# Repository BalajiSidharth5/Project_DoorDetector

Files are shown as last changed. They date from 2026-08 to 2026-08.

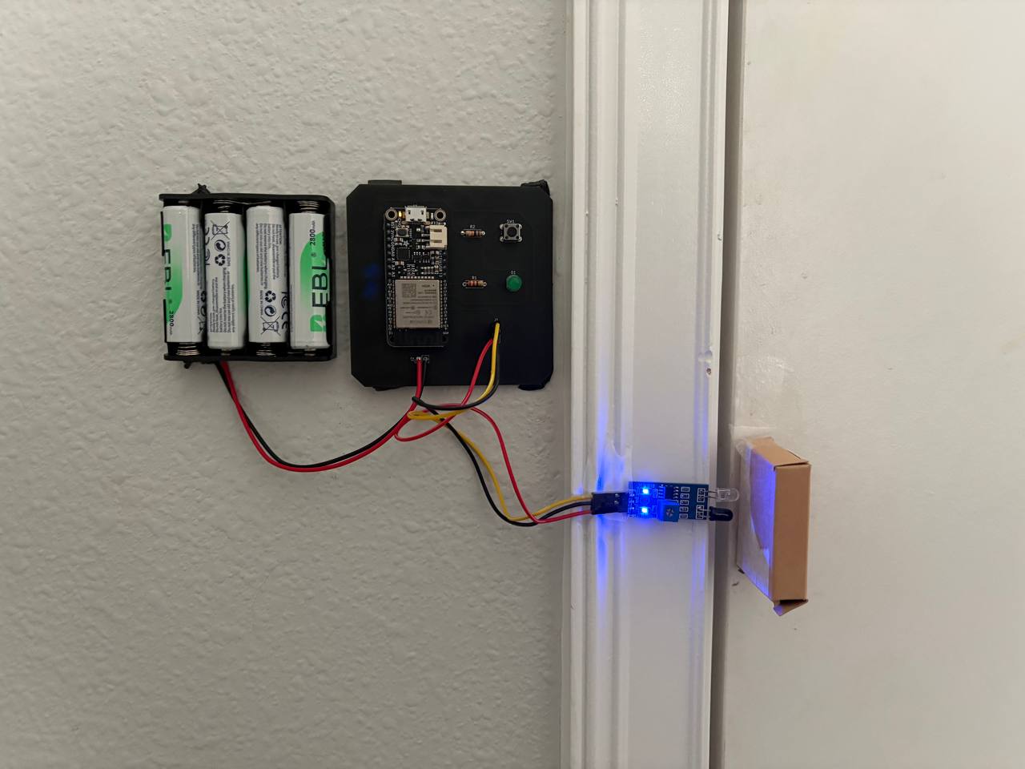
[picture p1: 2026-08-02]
Door_Detector_Working/Transmitter.jpg

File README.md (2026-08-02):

## Project_DoorDetector
# DOOR STATE DETECTOR
This project detects whether a door is open or closed using infrared reflection. It runs on two Adafruit HUZZAH32 boards.

# HOW IT WORKS
One HUZZAH32 sits at the door and reads the WWZMDiB 3 wire IR sensor. The sensor reflects IR off the door surface. When the door sits in front of the sensor, IR bounces back and the output reads one state. When the door swings open, the surface moves out of range and the output flips. A trim pot on the sensor sets the trigger distance.
The second HUZZAH32 acts as the receiver. It gets the door state and lights an LED to show open or closed.

# HARDWARE
- 2x Adafruit HUZZAH32
- WWZMDiB 3 wire IR sensor module
- 2x tactile pushbuttons, one on each HUZZAH32
- Status LED on each HUZZAH32, shows whether that board is awake
- LED on the receiver HUZZAH32, shows door open or closed state
- 220 ohm resistors for all LEDs
- 10k ohm resistors for both tactile buttons
- Rechargeable AA battery pack, wired directly to power and ground

# FIRMWARE
Button input is debounced in firmware on both boards.
Both boards run deep sleep to cut power draw. Each board wakes from deep sleep when you press its tactile button. The status LED on each board turns on when that board is awake and off when it drops back into deep sleep. This keeps both boards off when user does not need it. Utilized ESPnow library to communicate data between microcontrollers.

# POWER
The device runs on rechargeable AA cells instead of a lithium ion pack. Power and ground connect directly to the microcontroller with no charge circuit on board. Charging happens outside the device, in a standalone AA charger.

# STATUS
Breadboard prototype complete. PCB layout in progress in KiCad, targeting a compact 3D printed enclosure.

# NEXT STEPS
- Finish PCB layout in KiCad
- Design 3D printed enclosure around the board

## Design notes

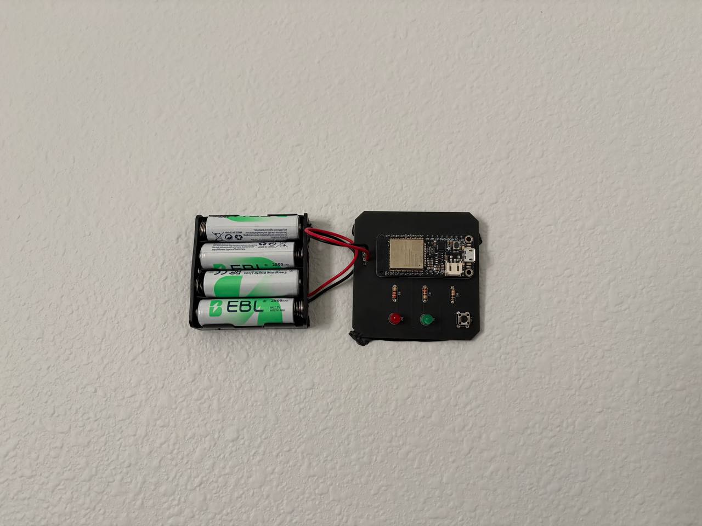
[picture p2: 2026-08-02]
Door_Detector_Working/Reciever.jpg

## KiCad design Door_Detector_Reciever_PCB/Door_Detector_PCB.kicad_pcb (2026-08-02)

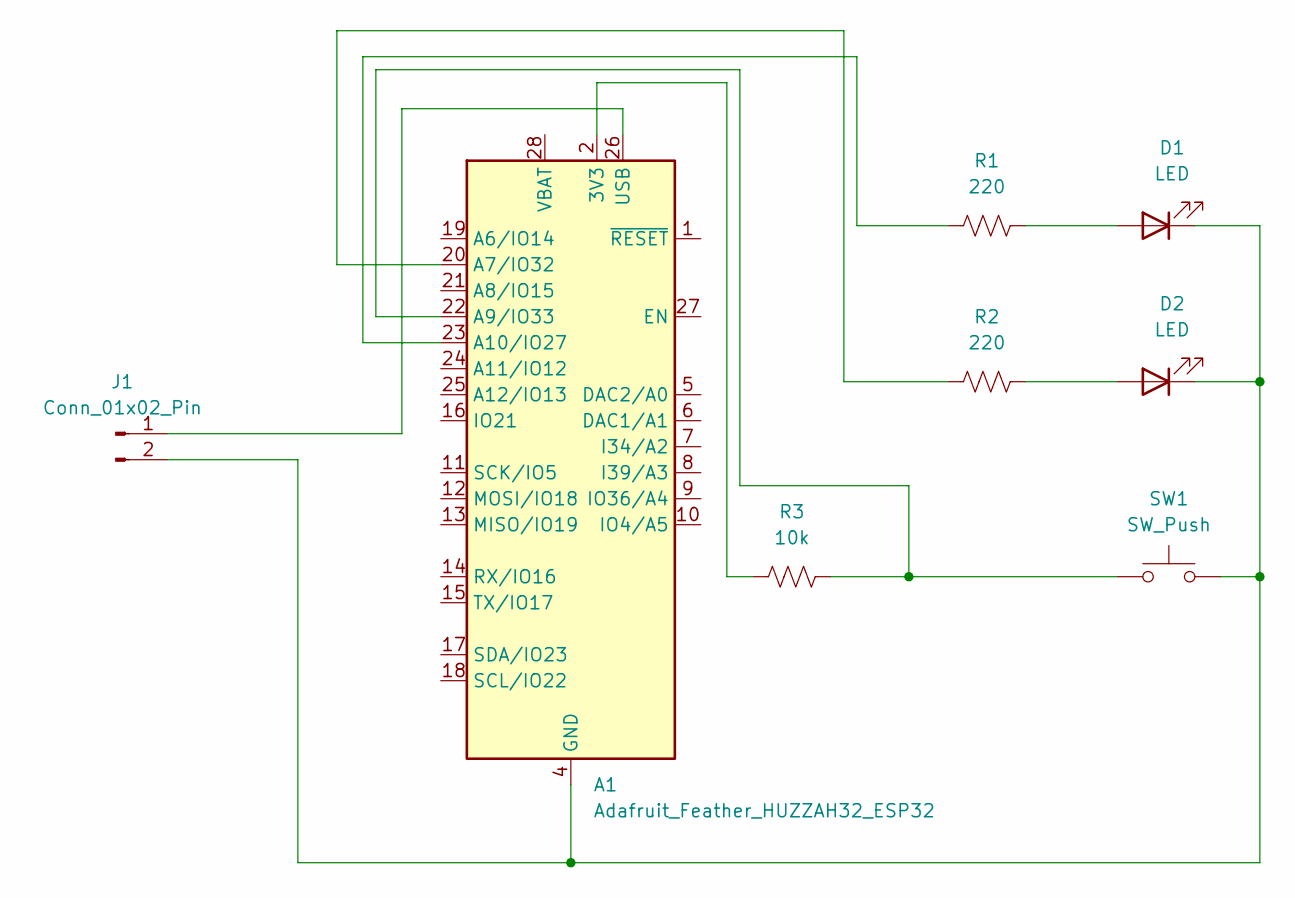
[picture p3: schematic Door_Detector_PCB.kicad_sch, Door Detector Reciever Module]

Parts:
A1: Adafruit_Feather_HUZZAH32_ESP32; Adafruit_Feather
D1, D2: LED; LED_D5.0mm
J1: Conn_01x02_Pin; PinHeader_1x02_P2.54mm_Vertical
R1, R2: 220; R_Axial_DIN0207_L6.3mm_D2.5mm_P7.62mm_Horizontal
R3: 10k; R_Axial_DIN0207_L6.3mm_D2.5mm_P7.62mm_Horizontal
SW1: SW_Push; SW_PUSH_6mm

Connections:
unnamed: A1.2 (3V3), R3.1
unnamed: A1.20 (A7/IO32), R2.1
unnamed: A1.22 (A9/IO33), R3.2, SW1.1
unnamed: A1.23 (A10/IO27), R1.1
unnamed: A1.4 (GND), D1.1 (K), D2.1 (K), J1.2, SW1.2
unnamed: A1.26 (USB), J1.1
unnamed: D1.2 (A), R1.2
unnamed: D2.2 (A), R2.2

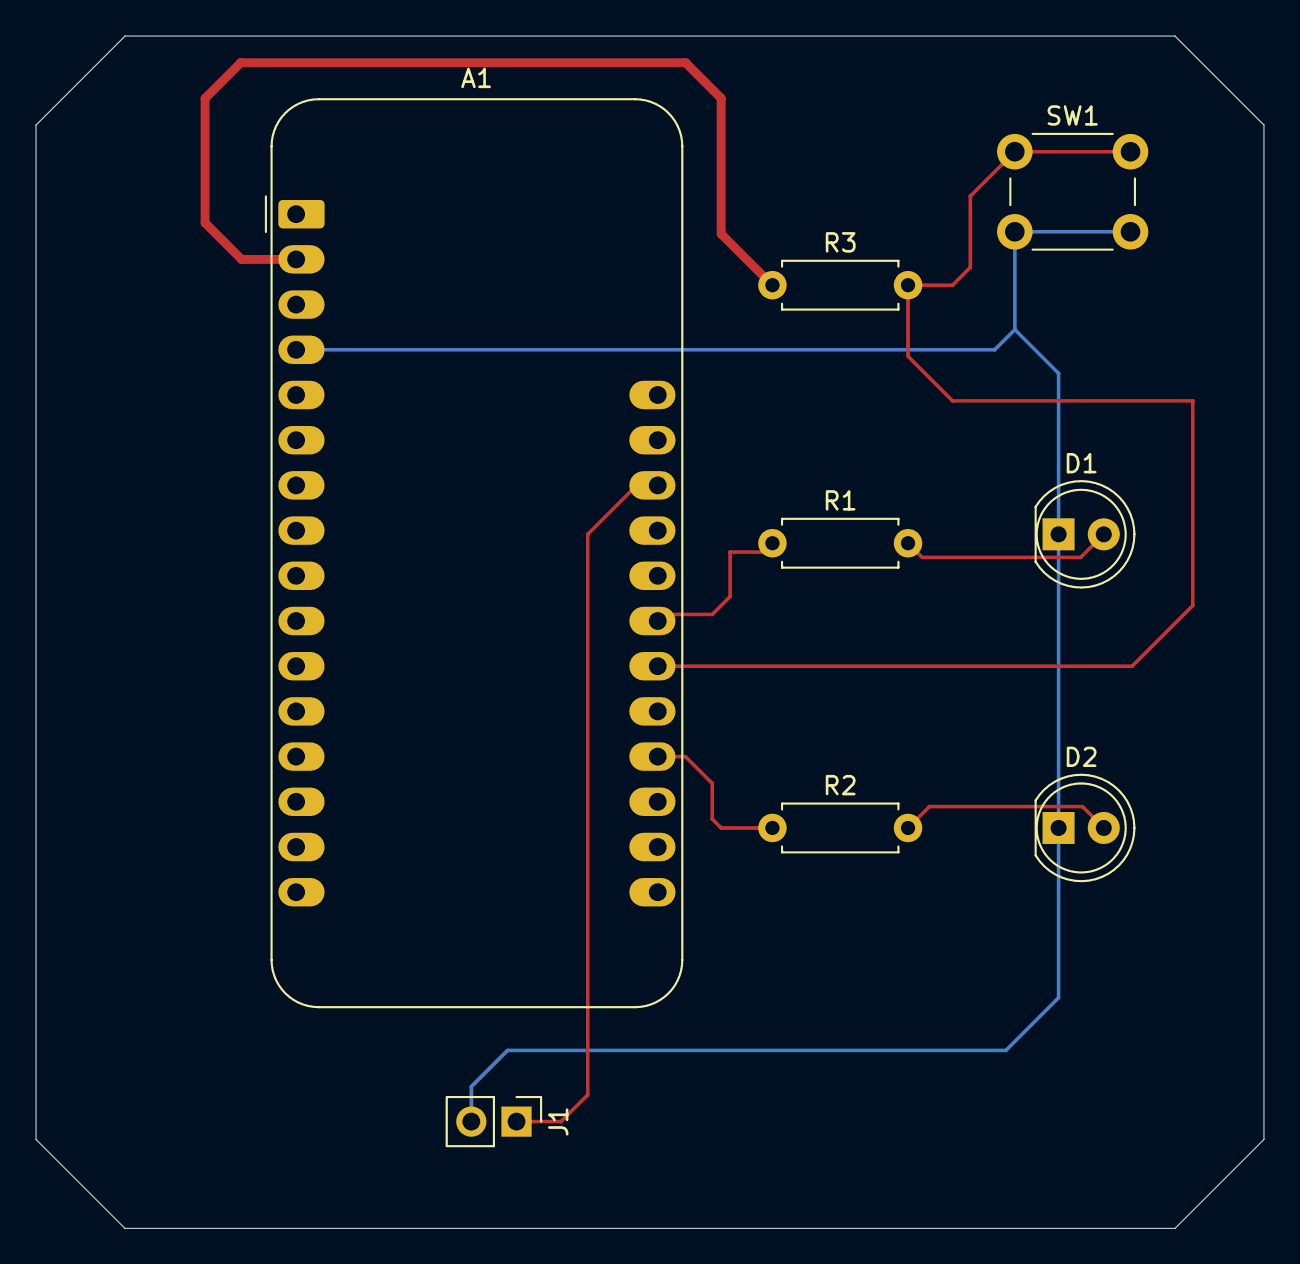
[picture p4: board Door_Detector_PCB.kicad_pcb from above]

Board: 2 copper layers, 69.0 x 67.0 mm, 8 parts (0 on the bottom side), 8 nets.

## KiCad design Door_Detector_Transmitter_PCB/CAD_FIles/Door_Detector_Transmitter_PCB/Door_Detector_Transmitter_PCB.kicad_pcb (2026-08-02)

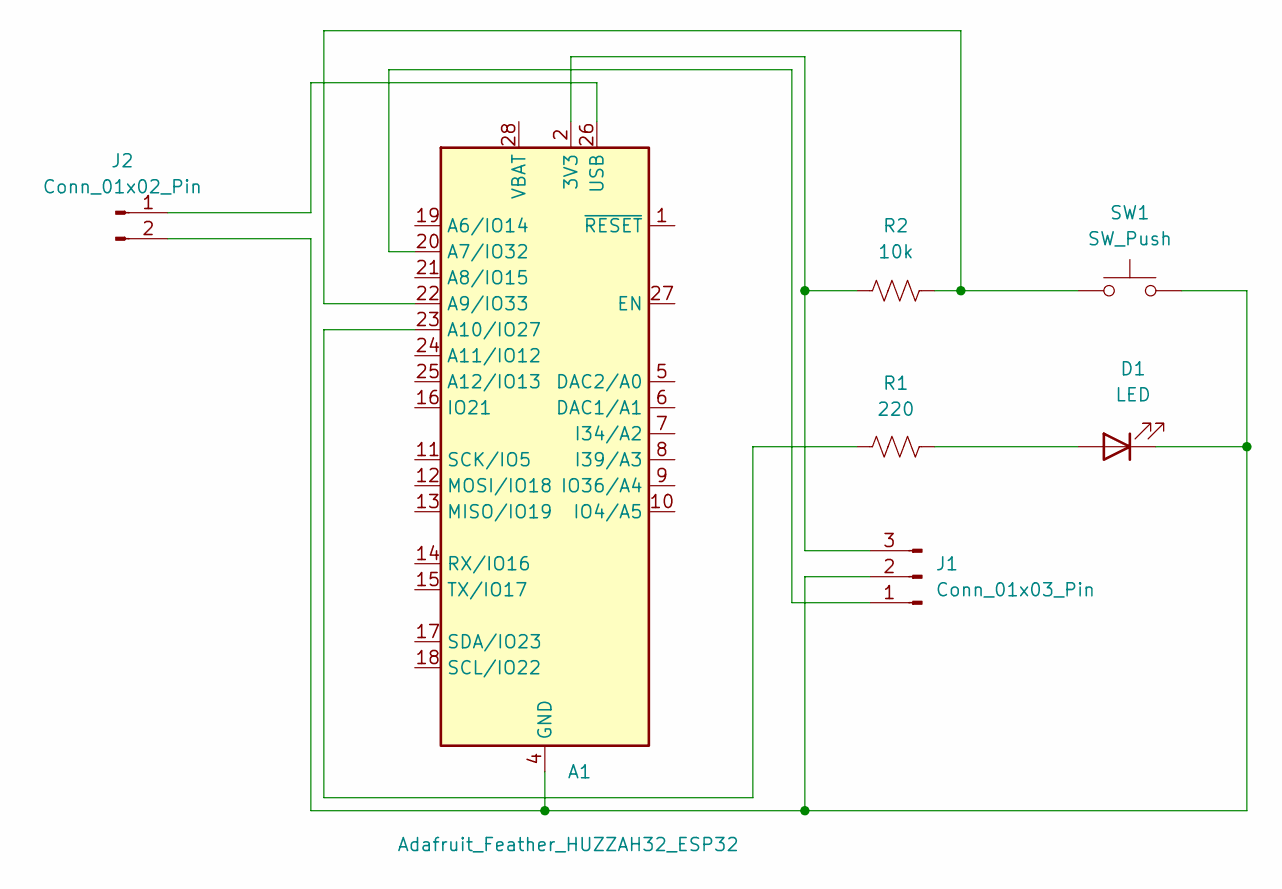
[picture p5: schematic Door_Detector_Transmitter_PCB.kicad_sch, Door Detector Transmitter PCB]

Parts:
A1: Adafruit_Feather_HUZZAH32_ESP32; Adafruit_Feather
D1: LED; LED_D5.0mm
J1: Conn_01x03_Pin; PinHeader_1x03_P2.54mm_Vertical
J2: Conn_01x02_Pin; PinHeader_1x02_P2.54mm_Vertical
R1: 220; R_Axial_DIN0207_L6.3mm_D2.5mm_P7.62mm_Horizontal
R2: 10k; R_Axial_DIN0207_L6.3mm_D2.5mm_P7.62mm_Horizontal
SW1: SW_Push; SW_PUSH_6mm

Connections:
unnamed: A1.2 (3V3), J1.3, R2.1
unnamed: A1.20 (A7/IO32), J1.1
unnamed: A1.22 (A9/IO33), R2.2, SW1.1
unnamed: A1.23 (A10/IO27), R1.1
unnamed: A1.4 (GND), D1.1 (K), J1.2, J2.2, SW1.2
unnamed: A1.26 (USB), J2.1
unnamed: D1.2 (A), R1.2

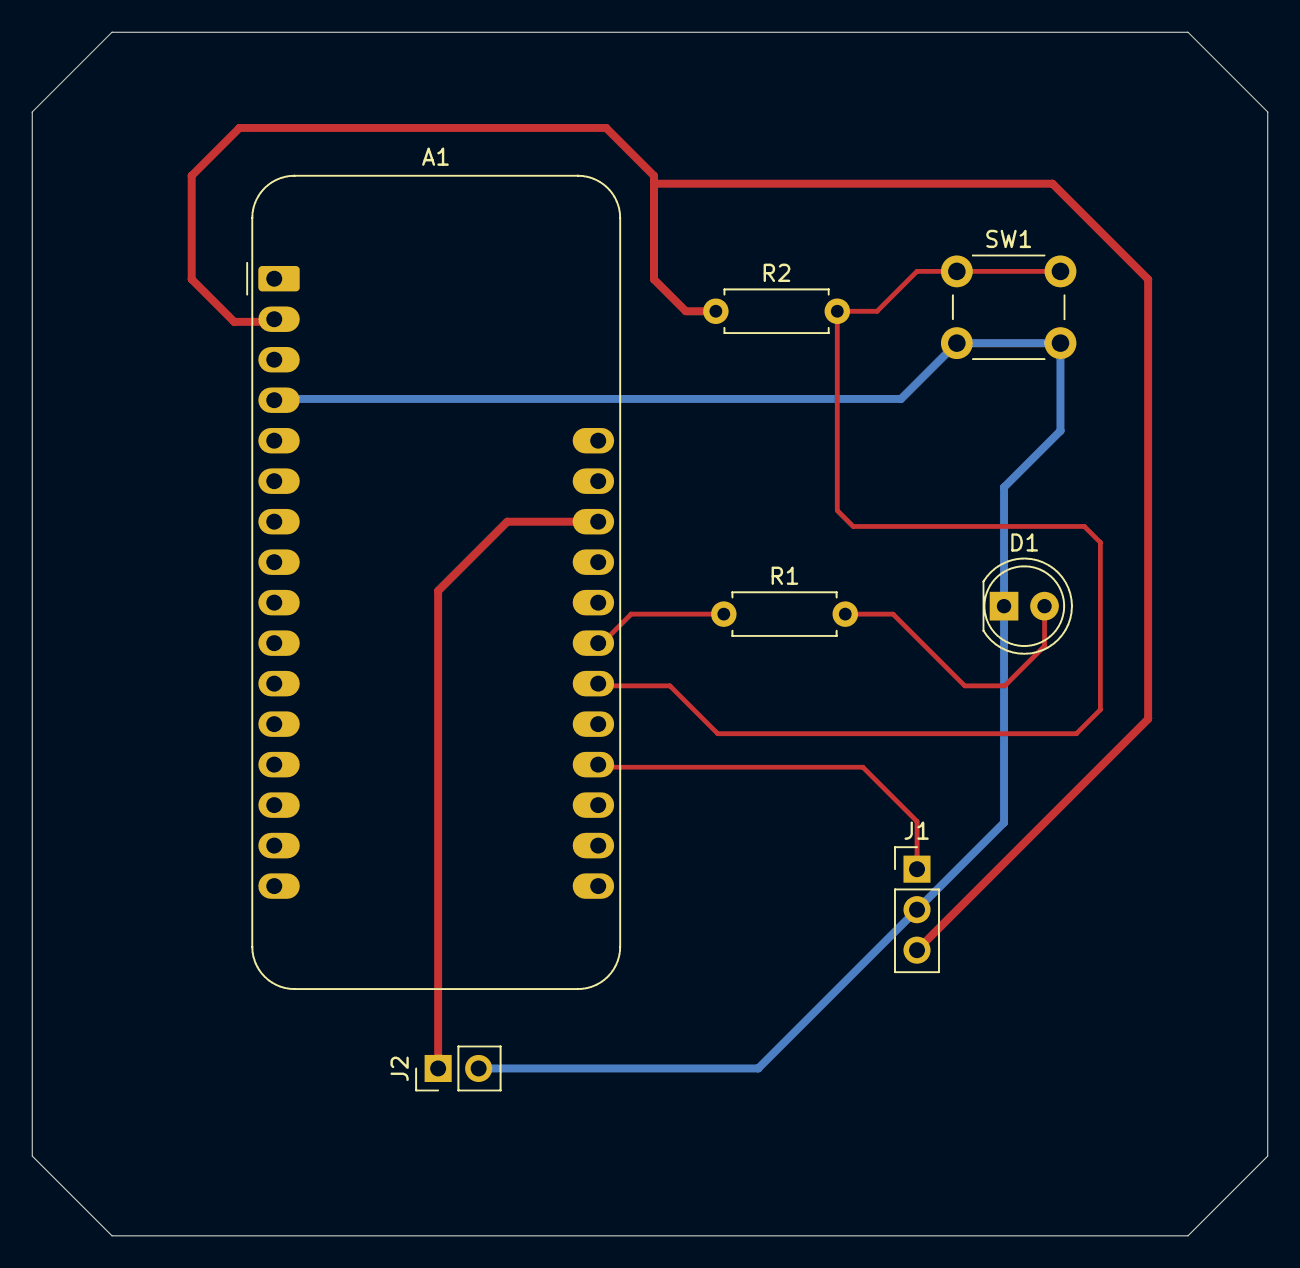
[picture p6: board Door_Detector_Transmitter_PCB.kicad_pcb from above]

Board: 2 copper layers, 77.5 x 75.5 mm, 7 parts (0 on the bottom side), 7 nets.

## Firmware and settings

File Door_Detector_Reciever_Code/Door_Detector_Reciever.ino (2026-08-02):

#include <esp_now.h>
#include "WiFi.h"
#include "esp_sleep.h"

// ===== Pins =====
const int buttonPin = 33;   // deep sleep button (active low)
const int statusLED = 27;   // on = awake, off = asleep
const int doorLED   = 32;   // on when transmitter senses nothing

// ===== Data structure (must match transmitter exactly) =====
typedef struct struct_message {
  bool objectDetected;
} struct_message;

struct_message myData;

void OnDataRecv(const esp_now_recv_info *info, const uint8_t *incomingData, int len) {
  if (len == sizeof(myData)) {
    memcpy(&myData, incomingData, sizeof(myData));

    if (myData.objectDetected) {
      digitalWrite(doorLED, LOW);    // something sensed -> LED off
    } else {
      digitalWrite(doorLED, HIGH);   // nothing sensed -> LED on
    }
  }
}

void goToSleep() {
  digitalWrite(statusLED, LOW);
  esp_sleep_enable_ext0_wakeup(GPIO_NUM_33, 0);
  esp_deep_sleep_start();
}

void checkButton() {
  if (digitalRead(buttonPin) == LOW) {
    delay(50);
    if (digitalRead(buttonPin) == LOW) {
      Serial.println("Button pressed, going to sleep");
      while (digitalRead(buttonPin) == LOW) { }
      goToSleep();
    }
  }
}

void setup() {
  Serial.begin(115200);
  delay(1000);

  pinMode(buttonPin, INPUT);
  pinMode(statusLED, OUTPUT);
  pinMode(doorLED, OUTPUT);

  digitalWrite(statusLED, HIGH);   // awake
  digitalWrite(doorLED, LOW);

  WiFi.mode(WIFI_STA);

  if (esp_now_init() != ESP_OK) {
    Serial.println("ESP-NOW init failed");
    return;
  }

  esp_now_register_recv_cb(OnDataRecv);
  Serial.println("Receiver ready");
}

void loop() {
  checkButton();
}

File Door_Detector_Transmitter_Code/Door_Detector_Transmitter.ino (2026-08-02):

#include <esp_now.h>
#include "WiFi.h"
#include "esp_sleep.h"

// ===== Pins =====
const int buttonPin = 33;   // deep sleep button (active low)
const int irSensor  = 32;    // IR sensor OUT
const int statusLED = 27;   // on = awake, off = asleep

// ===== Receiver's MAC address - FILL THIS IN =====
uint8_t receiverMAC[] = {0x38, 0x18, 0x2B, 0x2D, 0x6C, 0x98};

// ===== Data structure (must match receiver exactly) =====
typedef struct struct_message {
  bool objectDetected;
} struct_message;

struct_message myData;
esp_now_peer_info_t peerInfo;

unsigned long lastSend = 0;
const unsigned long sendInterval = 500;   // send every 500ms

void OnDataSent(const wifi_tx_info_t *info, esp_now_send_status_t status) {
  // not used, but required by the 3.x core signature
}

void goToSleep() {
  digitalWrite(statusLED, LOW);
  esp_sleep_enable_ext0_wakeup(GPIO_NUM_33, 0);  // wake on button press (LOW)
  esp_deep_sleep_start();
}

void checkButton() {
  if (digitalRead(buttonPin) == LOW) {
    delay(50);                                   // debounce
    if (digitalRead(buttonPin) == LOW) {
      Serial.println("Button pressed, going to sleep");  // runs BEFORE sleep
      while (digitalRead(buttonPin) == LOW) { }  // wait for release
      goToSleep();
    }
  }
}

void setup() {
  Serial.begin(115200);
  delay(1000);
  
  pinMode(buttonPin, INPUT);
  pinMode(irSensor, INPUT);
  pinMode(statusLED, OUTPUT);

  digitalWrite(statusLED, HIGH);   // awake

  WiFi.mode(WIFI_STA);
  
  if (esp_now_init() != ESP_OK) {
    Serial.println("ESP-NOW init failed");
    return;
  }
  
  esp_now_register_send_cb(OnDataSent);

  memcpy(peerInfo.peer_addr, receiverMAC, 6);
  peerInfo.channel = 0;
  peerInfo.encrypt = false;

  if (esp_now_add_peer(&peerInfo) != ESP_OK) {
    Serial.println("Failed to add peer");
    return;
  }
}

void loop() {
  checkButton();

  if (millis() - lastSend >= sendInterval) {
    lastSend = millis();
    myData.objectDetected = (digitalRead(irSensor) == LOW);  // LOW = detected
    esp_now_send(receiverMAC, (uint8_t *) &myData, sizeof(myData));
  }
}
